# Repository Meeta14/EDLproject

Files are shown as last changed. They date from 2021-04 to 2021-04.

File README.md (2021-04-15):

# EDLproject

Contains the code for measuring the State-of-Charge (SoC) of Lead-acid battery and also the PCB design of an analog circuit designed for LED intensity control of Solar-powered street lights.

Below are the schematic and board diagrams of the above-mentioned PCB.

sche
brd

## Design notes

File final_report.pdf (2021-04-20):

## Electronic Design Lab - EE 344

### Group - 33

## Solar-powered Street Light: LED intensity control

### Team Details

Group- 33

1. Avyakta Wrat - 180070010
2. Hitesh Kandala - 180070023
3. Meeta Malviya - 180070034

### Faculty Mentor

Prof Joseph John

### Problem Statement

At times due to cloudy sky or rain the solar panel present in the street light cannot produce the required amount of energy required to charge the battery. Full load is applied to this uncharged battery and hence the working time of the street light is low. Using battery at full load when it is low on charge, can damage it.
To address the above mentioned problem, we were expected to design a LED intensity control based on the state-of-charge (SoC) of the battery.

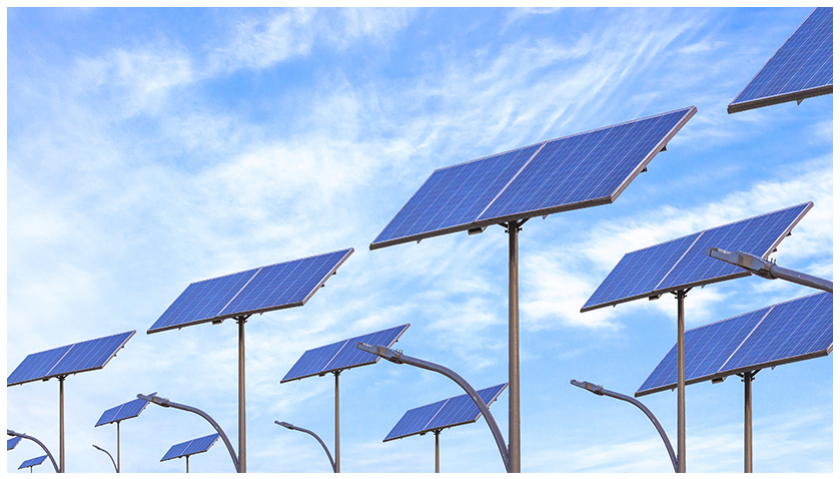
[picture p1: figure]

Figure 1

1

## 1 Design Approach

One of the possible solutions to vary the intensity of the LED lights is by varying the PWM’s duty cycle of the input voltage to the load LED’s. The proposed solution uses 555 Timer to vary the pulse width from 100% to 50% depending upon the battery voltage, hence increasing the discharge time of the battery and reducing the LED intensity by half. Using this, the street lights can be used for prolonged duration.

### 1.1 Proposed circuit

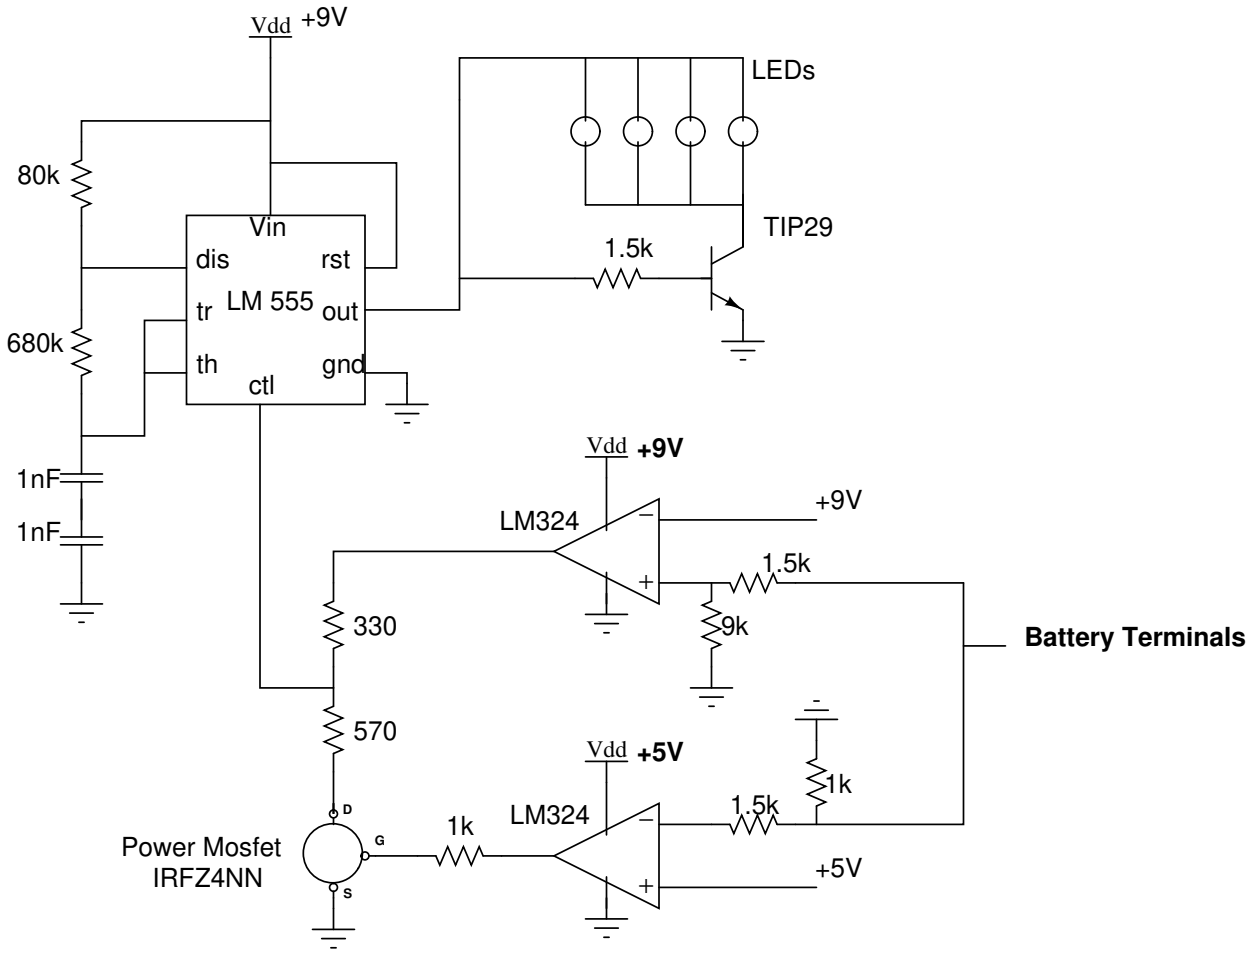
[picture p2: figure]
Vin; dis; rst; out; ctl; gnd; Vdd; Vdd +9V; LEDs; Power Mosfet; Battery Terminals 330; IRFZ4NN; TIP29

9V and 5V are supplied from respective voltage regulators

Figure 2

2

### Battery

1. The battery used is Panasonic UP-PW1245P1.
2. The Voltage when full charged is 12.7V
3. The battery has 50% charge at 11.6V.
4. The battery charge is below 10% or dead when no load voltage is 10.5V
5. Internal resistance of the battery is 20mΩ.

### Voltage regulators

In the design we have used 9V and 5V which are to be produced using voltage regulators.

To produce 9V | To produce 5V
The IC used to generate 9V output is LM7809. It gives 9V for Vin upto 24V The peak current can go upto 2.2A | The IC used to generate 5V output is LM7805. It gives 5V for Vin upto 20V The peak current can go upto 2.2A

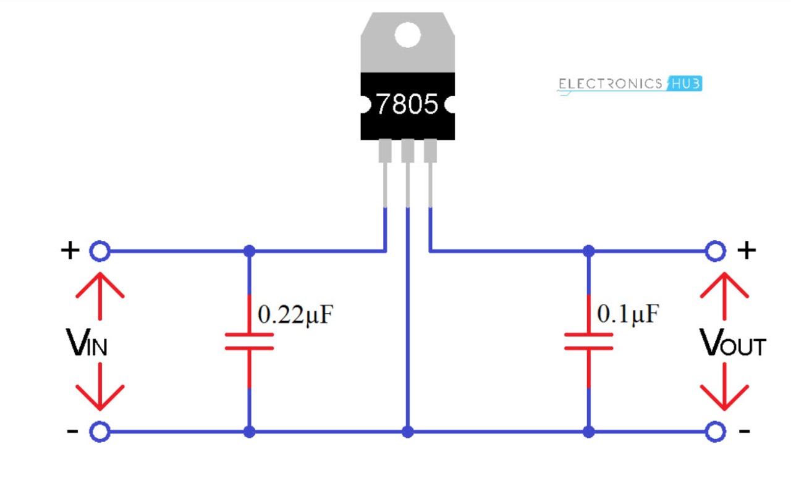
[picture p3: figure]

Figure 3: How to connect Voltage regulators

The above figure shows how voltage regulators must be connected in the circuit.
NOTE: This circuit is not shown in the above circuit, Voltages of 9V and 5V are shown independently to avoid unnecessary confusion.

3

### Timers

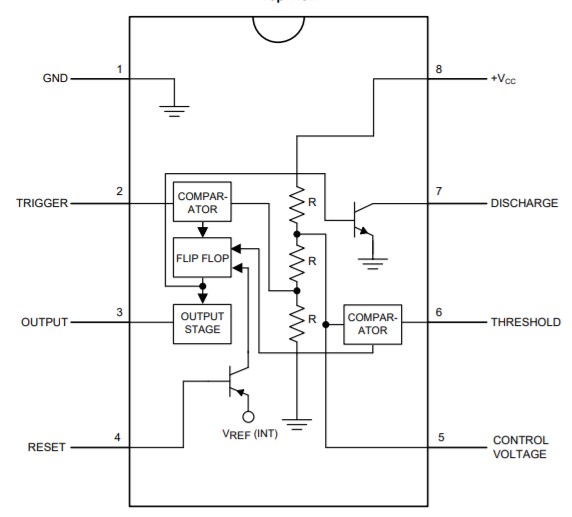
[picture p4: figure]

Figure 4

1. The 555-Timer used in the circuit is LM-555
2. Vcc can be from 5V-15V.
3. Vctl is used to vary the PWM cycle of the timer.

### 1.2 Calculations for Load and it’s specifications

The load that is being used is 5W LED strips.
The current required to be fed to the 5W load to operate it at full load is:

Pload = 5W
Vout (from 555 timer) = 9V

Iload =

Pload

Vout

= 555.56 mA

The resistor needed to maintain the current with the BJT used is derived as follows:

β = 100; | VB = 0.7 V
IC = Iload = 555.56 mA; | IB = 5.56 mA

RB =

9 − VB
IB
∴ RB = 1.49 kΩ ≈ 1.5 kΩ

The NPN transistor BJT used is TIP29-BP, which has max collector current (Ic) =1A specifications.

4

### 1.3 Calculations Duty cycle and frequency

With control voltage applied at pin 5, we can control duty cycle and freq as follows:

1. Let voltage applied at pin 5 be Vctl and Vctl <= 9 V.
2. Then the voltages map as follows:
2
3

Vcc −→ Vctl

1
3

Vcc −→

Vctl
2
3. Calculating “On” (charging) time:
Taking the moment that the capacitor starts charging to be t = 0 we can state the charging equation for the capacitor as:

V (t) = (Vcc − 0.5Vctl)(1 − e

−t
τc ) + 0.5Vctl

where, charging time constant τc = (RA + RB)C Now, V (ton) = Vctl gives:
ton = τc ln
Vcc − 0.5Vctl

Vcc − Vctl

4. Calculating “Off” (discharging) time:
Now we will show that the ”off” time is not dependent on Vctl. We know that a discharging capacitor can be modeled with the following relation:

V (t) = V0e

−t
τd

where, V0 = Vctl i.e initial voltage and discharging time constant τd = RBC Now, V (tof f ) = 0.5Vctl gives:

tof f = τd ln (2)

5. Duty cycle is given as follows:

D =

ton

ton + tof f

=

τc ln (Vcc−0.5Vctl
Vcc−Vctl

)

τc ln (Vcc−0.5Vctl
Vcc−Vctl

) + τd ln (2)

6. Frequency is given as:

f =

1

ton + tof f

=

1

τc ln (Vcc−0.5Vctl
Vcc−Vctl

) + τd ln (2)

To maintain the clock frequency around 1kHz, we choose RA = 80 kΩ, RB = 680 kΩ and C = 0.5 nF.
So, in our case when Vcc = 9V , for achieving 100% duty cycle, Vctl should be 9V and for achieving 50% duty cycle, Vctl should be 5.68V. As we can observe that the frequency varies as Vctl varies. Hence for 100% PWM the frequency is around 1kHz, for 50% it is 2kHz.

5

### 1.4 Switching Circuit

The OPAMP used for the circuit as a comparator is LM324.The supply voltage can be of 3V-32V. The maximum output current is of 20mA
The switching logic creates the output such that,
1. The OP-AMP-1 outputs 1 (high=9V) when the battery voltage is more than 10.5V.
2. The OP-AMP-2 outputs 1 (high=5V) when the battery voltage is less than 11.6V
3. Then the output of OP-AMP -2 decides whether the MOSFET is supposed to turn on or off.
4. The VDD is 0V (output low of OM-AMP1) when battery is dead.
OP AMP1/2 = ON/OF F | MOSF ET = OF F , Vout = Vctl = 9V
OP AMP1/2 = ON/ON | MOSF ET = ON, Vout = Vctl = 5.68V ≈ 5.7V
OP AMP1 = OF F | Vout = Vctl = 0V

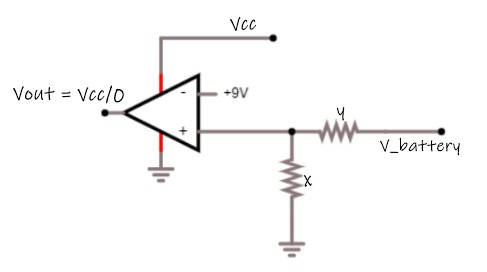
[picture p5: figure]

(a) Opamp 1

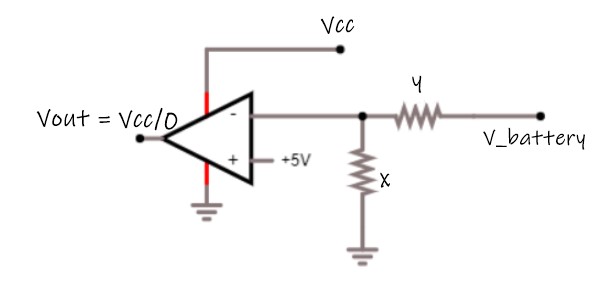
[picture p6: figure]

(b) Opamp 2

Figure 5

OP-AMP-1 Calculations
We want output high for VBattery > 10.5, I have put a V− = 9V , hence,

V− = 9V > V+; Vbattery ≤ 10.5

9 ≥ Vbattery ×

x
x + y
9x + 9y ≥ 10.5x
9y ≥ 1.5x
Chosen resistor values are x = 1.5kΩ; y = 9kΩ

6

OP-AMP-2 Calculations
We want output low for 12.7 > VBattery > 11.6, I have put a V+ = 5V , hence,

V+ = 5V > V−; 11.6 ≤ Vbattery ≤ 12.7

11.6 ×

x
x + y

≤ 5 ≤ 12.7 ×

x
x + y
11.8x ≤ 5x + 5y ≤ 12.7x
6.8x ≤5y ≤ 7.7x
1.36x ≤y ≤ 1.54x
Chosen resistor values are x = 1kΩ; y = 1.5kΩ

MOSFET Calculations
The MOSFET we decided to use is IRFZ44N. It has a max Gate threshold of 4V.The VGS can go upto 20V. It has a max current rating of 49A.
MOSF ET = ON | VGS = 5V | Vth = 4V | VDD = 9V
MOSF ET = OF F | VGS = 0V | Vth = 4V | VDD = 9V

As noted in the above section for 50% cycle we need to have Vout = 5.68 ≈ 5.7V

Functioning of the MOSFET as a switch can be denoted by the following figure.

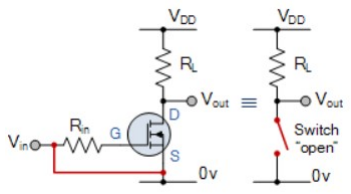
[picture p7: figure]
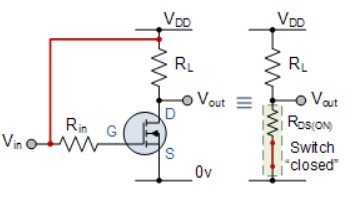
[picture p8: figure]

(a) switch on | (b) switch off

Figure 6

1. The internal resistance of the MOSFET RDS is of 19mΩ and hence is neglected.
2. We need to drop the potential of 9V to 5.7 volts and give it as input to 555 timer.
3. This is achieved by using 570Ω (470 + 100) and 330Ω resistors.
4. The max current through OMAMP and MOSFET is of 10mA which is well below the max rated current.

7

### 1.5 Proposed method for SOC calulations

To calculate the SOC,

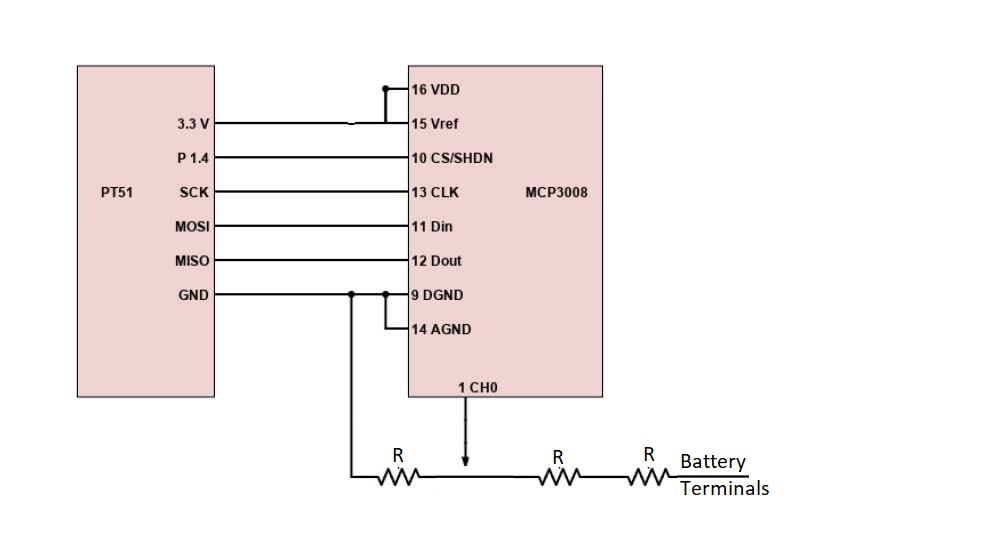
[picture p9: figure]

Figure 7: connections for pt-51

1. We are using IC MCP3008 (10-bit Analog-to-Digital converters (ADC) with SPI) to calcuate the voltage across the battery.
2. The circuit is connected as shown above.
3. The output of the IC is in the format: XXXXX mV, hence even after using the voltage divider we have not compromised much on the precision.
4. The range of output will be

10.5V ≤ 3Vmeasured ≤ 12.7V 3.5V ≤ Vmeasured ≤ 4.23V

5. We measure the 10 instances of the battery voltage and take the minimum voltage. This voltage will correspond to when LEDs are on (given the measured voltage is more than 10.5V).

8

6. Because we want open circuit voltage we make the following calculations (done by micro controller)

Vbattery − ItotalRinternal = Vmeasured
V measured = (measurement made by ADC) × 3 Itotal ≈ 560mA (when LED’s are on)

Rinternal = 20mΩ

Vbattery = ItotalRinternal + Vmeasured = 0.0112V + Vmeasured

The link to the codes for the above method is, https://github.com/Meeta14/EDLproject

### 1.6 Cost of Billing

The total cost is shown below,
NOTE: Panasonic UP-PW1245P1 of worth Rs. 2252 and LED load is taken as given.
Item | Quantity | Single Unit Price (Rs) | Total Price (Rs)
LM324 | 2 | 11 | 22
LM555 | 1 | 10 | 10
IC 7805 | 1 | 9 | 9
IC 7809 | 1 | 10 | 10
IRFZ44N | 1 | 20 | 20
TIP29 BJT | 1 | 32 | 32
100Ω Resistor | 1 | 0.5 | 0.5
330Ω Resistor | 1 | 2 | 2
470Ω Resistor | 1 | 1 | 1
1kΩ Resistor | 2 | 0.5 | 1
1.5kΩ Resistor | 3 | 1 | 3
9kΩ Resistor | 1 | 1 | 1
40kΩ Resistor | 3 | 1 | 3
80kΩ Resistor | 1 | 1 | 1
680kΩ Resistor | 1 | 2 | 2
1nF Capacitor | 2 | 0.5 | 1
0.1uF Capacitor | 2 | 0.5 | 1
0.22uF Capacitor | 2 | 0.5 | 1
| | Total Cost | 120.5

NOTE: The cost of PCB printing is not included in it.

9

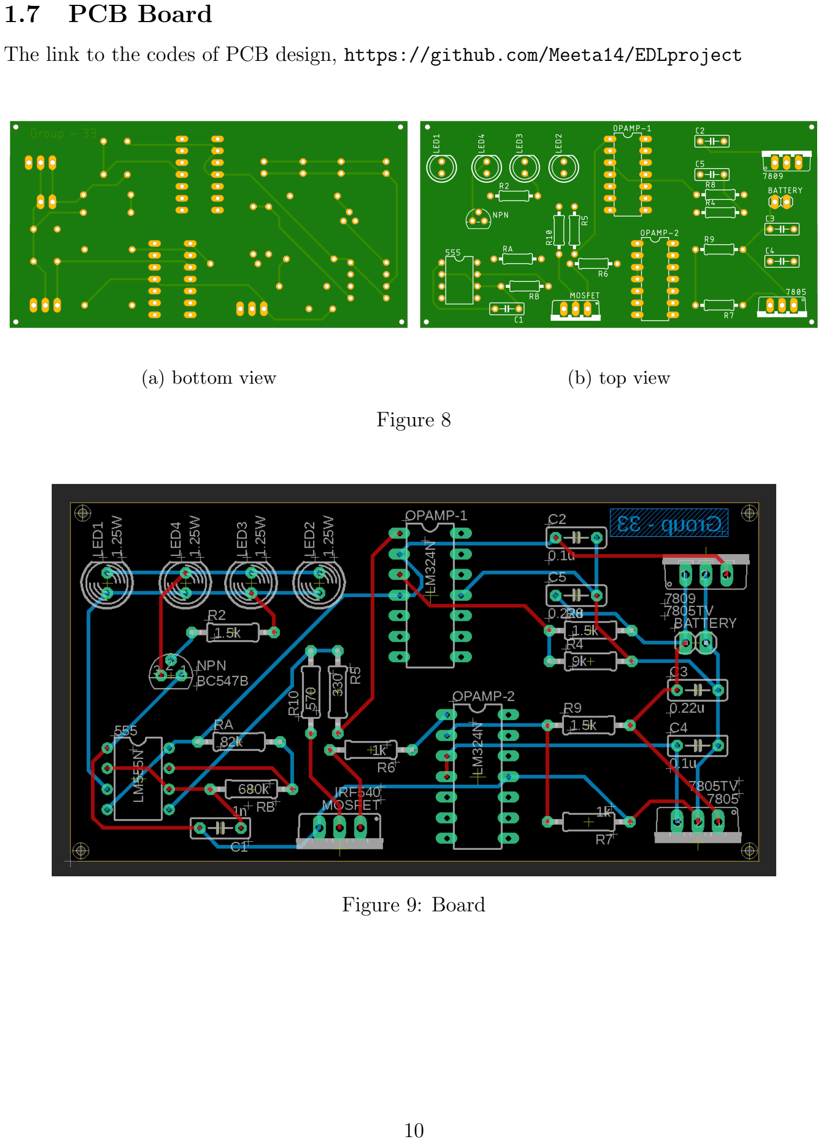
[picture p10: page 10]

### 1.7 PCB Board

The link to the codes of PCB design, https://github.com/Meeta14/EDLproject

(a) bottom view | (b) top view

Figure 8

Figure 9: Board

10

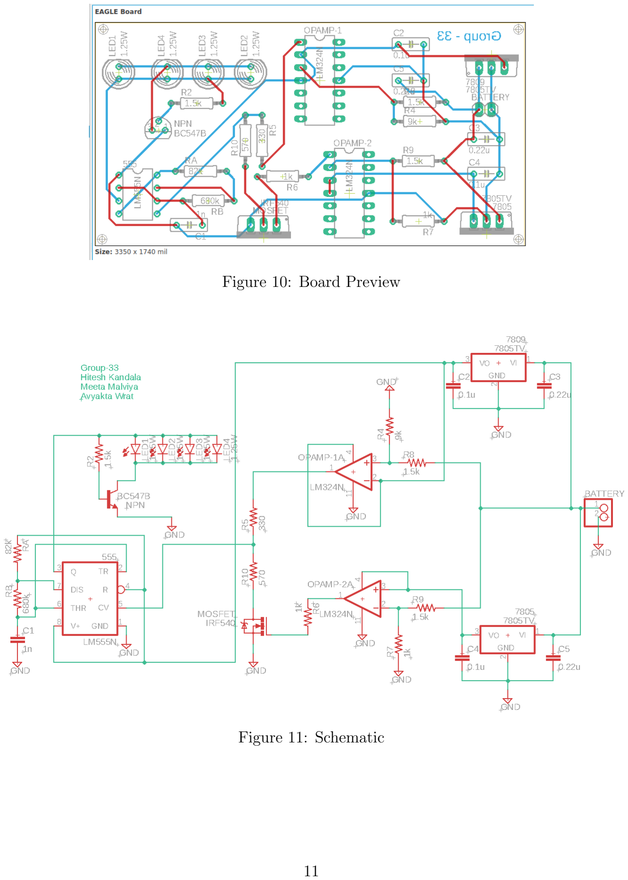
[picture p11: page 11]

Figure 10: Board Preview

Figure 11: Schematic

11

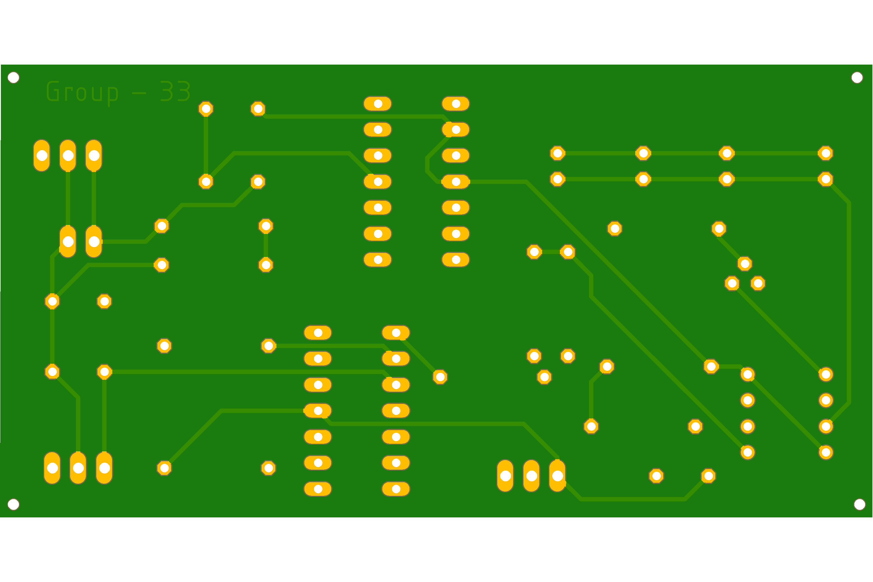
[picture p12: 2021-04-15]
pcb-design/pcb_bottom.png

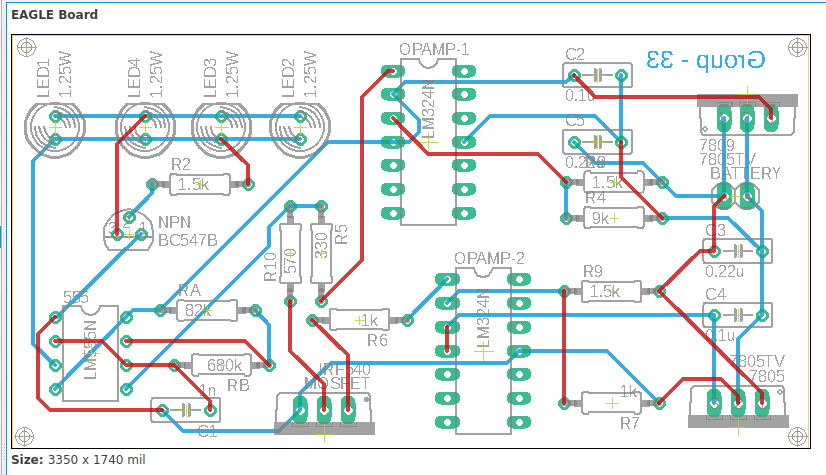
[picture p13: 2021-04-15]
pcb-design/preview.png

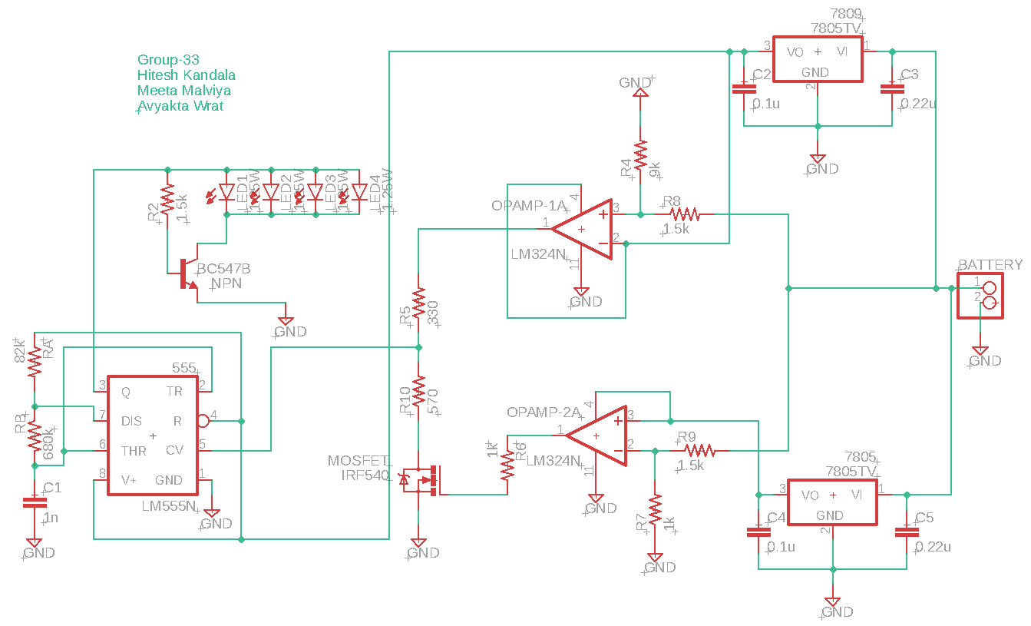
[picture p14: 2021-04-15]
pcb-design/sche.png

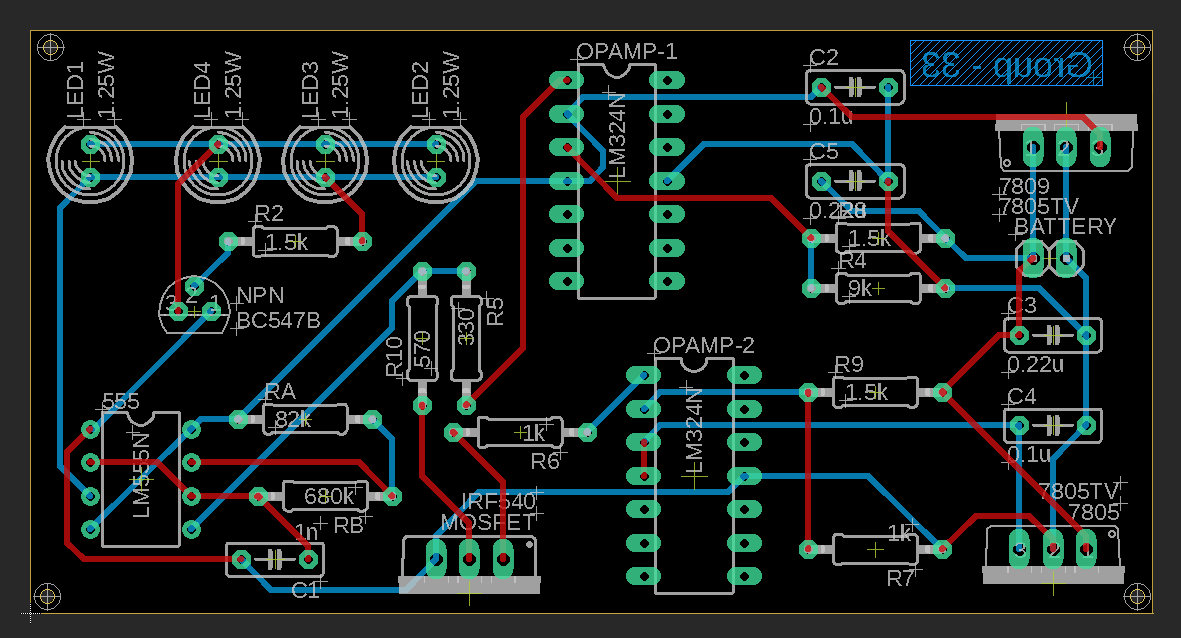
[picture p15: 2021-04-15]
pcb-design/brd.png

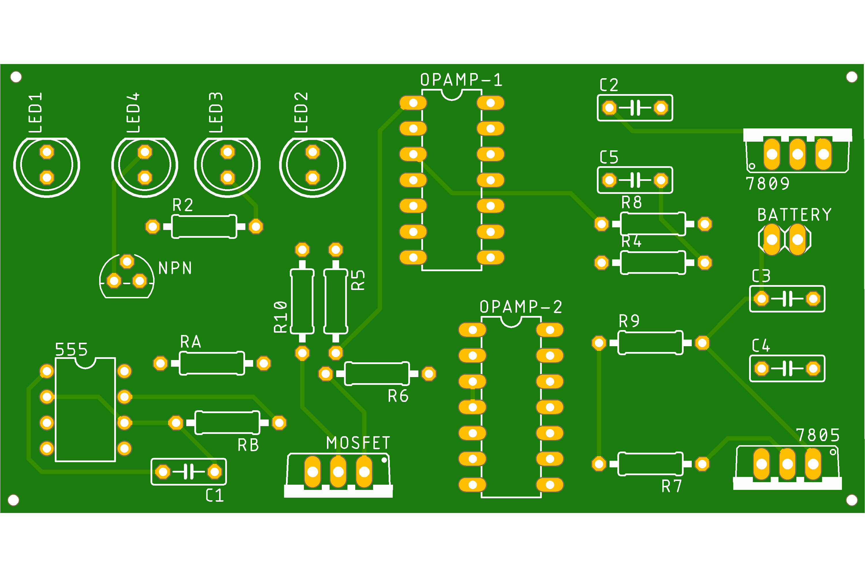
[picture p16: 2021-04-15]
pcb-design/pcb_top.png

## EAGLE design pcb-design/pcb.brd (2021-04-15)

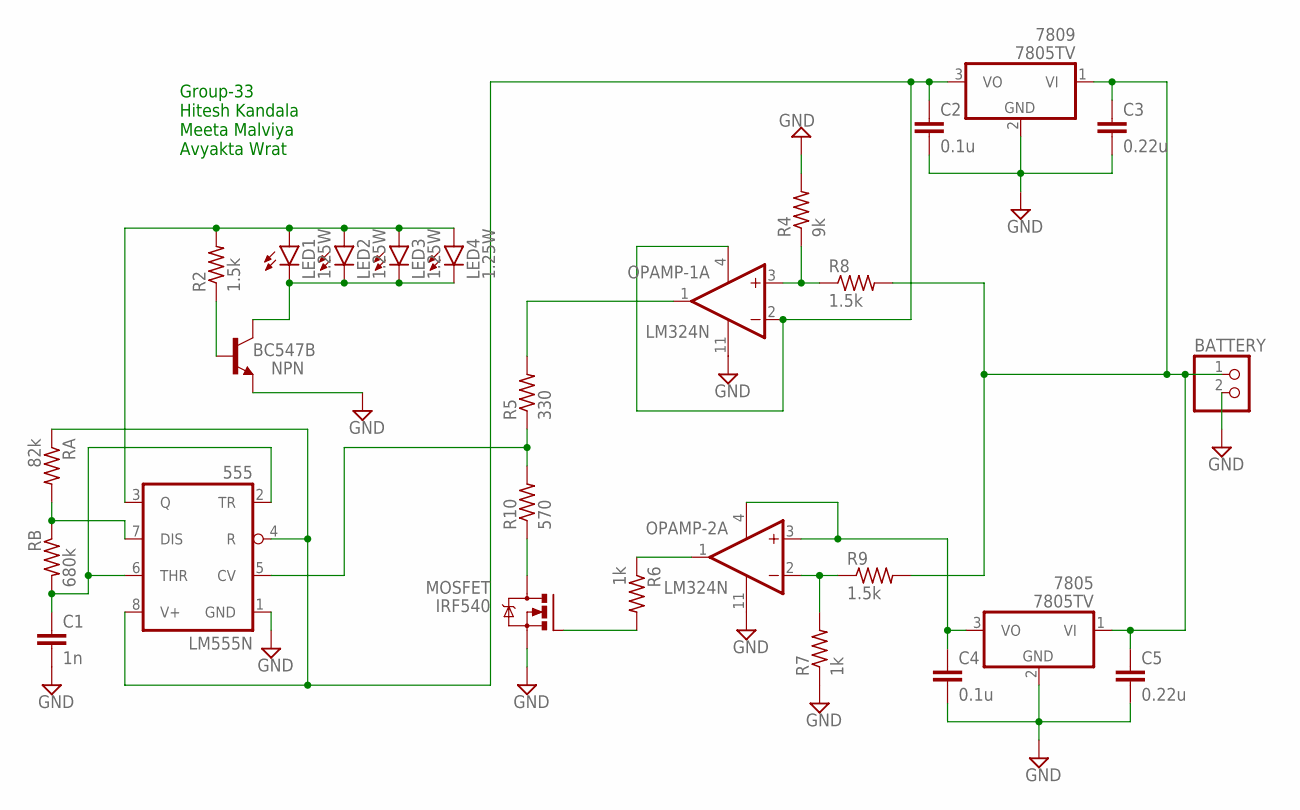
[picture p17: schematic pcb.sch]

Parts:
555: LM555N; DIL08
7805, 7809: 7805TV; TO220V
BATTERY: PINHD-1X2; 1X02
C1: 1n; C050-025X075
C2, C4: 0.1u; C050-025X075
C3, C5: 0.22u; C050-025X075
LED1, LED2, LED3, LED4: 1.25W; LED5MM
MOSFET: IRF540; TO220BV
NPN: BC547B; TO92
OPAMP-1, OPAMP-2: LM324N; DIL14
R2, R8, R9: 1.5k; 0207/10
R4: 9k; 0207/10
R5: 330; 0207/10
R6, R7: 1k; 0207/10
R10: 570; 0207/10
RA: 82k; 0207/10
RB: 680k; 0207/10

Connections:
GND: 555.1 (GND), 7805.2 (GND), 7809.2 (GND), BATTERY.2, C1.2, C2.2, C3.2, C4.2, C5.2, MOSFET.S, NPN.1 (E), OPAMP-1.11 (V-), OPAMP-2.11 (V-), R4.2, R7.1
unnamed: 555.4 (R), 555.8 (V+), 7809.3 (VO), C2.1, OPAMP-1.2 (-IN), OPAMP-1.4 (V+), RA.1
unnamed: 555.2 (TR), 555.6 (THR), C1.1, RB.2
unnamed: 555.3 (Q), LED1.A, LED2.A, LED3.A, LED4.A, R2.2
unnamed: 555.7 (DIS), RA.2, RB.1
unnamed: 7805.1 (VI), 7809.1 (VI), BATTERY.1, C3.1, C5.1, R8.2, R9.2
unnamed: NPN.2 (B), R2.1
unnamed: OPAMP-1.3 (+IN), R4.1, R8.1
unnamed: OPAMP-2.2 (-IN), R7.2, R9.1
unnamed: 7805.3 (VO), C4.1, OPAMP-2.3 (+IN), OPAMP-2.4 (V+)
unnamed: OPAMP-2.1 (OUT), R6.1
unnamed: 555.5 (CV), R5.1, R10.2
unnamed: OPAMP-1.1 (OUT), R5.2
unnamed: MOSFET.D, R10.1
unnamed: MOSFET.G, R6.2
unnamed: LED1.K (C), LED2.K (C), LED3.K (C), LED4.K (C), NPN.3 (C)

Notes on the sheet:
Group-33 Hitesh Kandala Meeta Malviya Avyakta Wrat

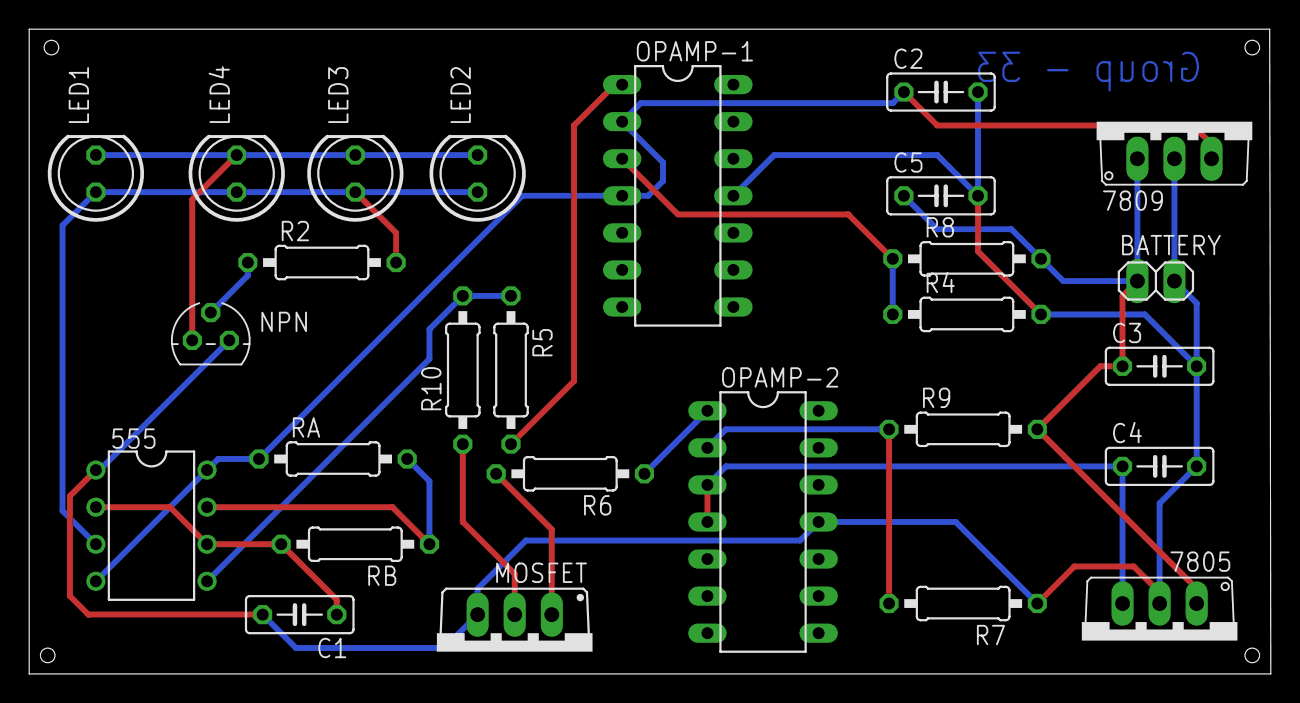
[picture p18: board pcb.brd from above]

Board: 2 copper layers, 85.1 x 44.2 mm, 27 parts (0 on the bottom side), 16 nets.

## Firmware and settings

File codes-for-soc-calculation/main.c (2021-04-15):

/********************
EE337: ADC IC MCP3008 interfacing with pt-51
(1) Complete spi_init() function from spi.h 
(2) Uncomment LM35 interfacing code from main function
		Choose appropriate scaling factor for converting temperature 
		sensor reading sampled using ADC such that it will be in 
		degree Celsius and display it on the LCD)
*********************/

#include <at89c5131.h>
#include "lcd.h"																				//Driver for interfacing lcd 
#include "mcp3008.h"																		//Driver for interfacing ADC ic MCP3008


char adc_ip_data_ascii[6]={0,0,0,0,0,'\0'};							//string array for saving ascii of input sample
code unsigned char display_msg1[]="Volt.: ";						//Display msg on 1st line of lcd
code unsigned char display_msg2[]=" mV";								//Display msg on 2nd line of lcd
unsigned char display_msg3[]={0,0,0,'.',0,' ',223,'C','\0'};//"xxx °C", Display msg on 2nd line of lcd
code unsigned char display_msg4[]="Temp.: ";						//Display msg on 2nd line of lcd
unsigned int array_adc[10];
unsigned int idx=0;
unsigned int x;	
unsigned int min_value=0;
unsigned int i=0;

void msdelay2(unsigned int time)
{
	int i,j;
	for(i=0;i<time;i=i+2)
	{
		for(j=0;j<382;j=j+2);
	}
}

void main(void)
{
	int j=0;
	unsigned int adc_data=0;
	//float temperature;
	
	spi_init();																					
	adc_init();
  lcd_init();	
	
	while(1)
	{
		if(idx==9){	                            // when we have completed 10 instances of measurement
			i=0;
			min_value=array_adc[0];
			for(i=1;i<10;i++){                     // find the minimum voltage
					if(min_value>array_adc[i]){
						min_value=array_adc[i];
					}
			}
			adc_data = (unsigned int) (min_value*3.2258); 							//Converting received 10 bits value to milli volt (3.3*1000*i/p /1023)	
			lcd_cmd(0x80);																			//Move cursor to first line
			lcd_write_string(display_msg1);											//Display "Volt: " on first line of lcd
			
			if(adc_data>10500){                                // if the voltage is more than 10% V ratings we add the  IR component
					adc_data=adc_data+0.0112;
			}
			int_to_string(adc_data,adc_ip_data_ascii);					//Converting integer to string of ascii
			
			lcd_write_string(adc_ip_data_ascii);								//Print analog sampled input on lcd
			lcd_write_string(display_msg2);											//Display "XXXXX mV"
					
			idx=0;
		}
	 	 
		x = adc(0);																					//Read analog value from 0th channel of ADC Ic MCP3008
    array_adc[idx] = x;                                // keep the array updated
		msdelay2(2);
	}
}

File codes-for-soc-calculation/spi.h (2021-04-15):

/**********************************************************
This header file contains function related uC 8051 SPI module. 
It has functions to initialize spi module and to communicate with SPI slave 
***********************************************************/

//preprocessor directives for guarding against multiple inclusion of header files, read compiler user guide for more information

#ifndef spi_h																						//if identifier spi_h is not defined then goto next line
	#define spi_h 1																				//Define spi_h identifier and assign constant 1 to it 
#endif																									//end if directive

//Declaration of functions which are contained in this header file

void spi_init(void);																		//Initialize SPI module 
unsigned long int spi_trx(unsigned long int spi_data_tx);				//Takes 3 bytes as an input and send it to SPI slave IC and returns 3 bytes which are received from slave
void spi_interrupt(void);																//SPI ISR 																												


//Variable declaration

bit transmit_completed= 0;															//To check if SPI data transmit is complete
unsigned char temp_spi_data;														//Temporary variable

//Function definition


/**********************************************************
  spi_init(): 
	
	Initialization function to be completed
	Initializes SPI peripheral for interfacing with MCP3008, 
	Choose appropriate SPCON value by referring to 
	MCP3008 and AT89C5131 datasheets  	
***********************************************************/
void spi_init(void)
{
	/*
			Configure SPCON=0x__ is not a bit addressable sfr
																												
			(1) Configure MSTR to set uC in Master mode
			(2) Configure SSDIS to disable SSBAR thus 
					P1.1(SSBAR) will be available as standard I/O pin 	             	 	 
			(3) Configure clock polarity s.t. sck from uC set to 0 in idle state
					Refer to SPCON register table no 19-3 from AT89C5131 datasheet
			(4) Configure clock phase i.e. CPHA: Refer SPI timing 
					diagram of ADC IC (figure no. 6-1 in MCP3008 datasheet)
					first and then table no 19-3, figure no. 19-4 to 19-6 in AT89C5131 datasheet
					to choose appropriate CPHA value
			(5) Fclk/16 & Fclk Periph=12MHz ,thus BAUD RATE=750KHz
	
			(6) Enable SPI interrupt (i.e. configure IEN1 and EA)
			(7) Enable SPI module (i.e. configure SPCON )
*/	
	SPCON =0x33;			//0011 0011																																																					
	IEN1|= 0x04;																						//enable spi interrupt IEN1 |= 0x__
	EA= 1;																									//enable interrupts EA=_; 
	SPCON|= 0x40;		//0100 0000
	//Enable spi module
/*	
	SPR2 SPEN SSDIS MSTR CPOL CPHA SPR1 SPR0
	MSTR 0->SPI as a Slave. 1-> SPI as a Master.
*/
}

/**********************************************************
  spi_trx(): 
	
	Transmits 3 bytes to SPI slave and receive 3 bytes. 
	These 3 bytes are packed into 4 bytes as long datatype.
***********************************************************/
unsigned long int spi_trx(unsigned long int spi_data_tx)
{
	//declaration of local variables 
	unsigned long int spi_data_rx;
	unsigned char spi_data_3,spi_data_2,spi_data_1;
	
	//Send 3rd byte
		transmit_completed = 0;
		
		SPDAT = (spi_data_tx>>16)%256;											//Sending most significant byte of data to SPI slave 
	
		while(!transmit_completed);													//Wait till transmission is complete. 	
			spi_data_3	=	temp_spi_data ;											//Most significant byte will be received  
	
	//Send 2nd byte
		transmit_completed=0;
		SPDAT = (spi_data_tx>>8)%256;												//Extracting and sending byte between MS and LS byte to SPI slave	
		
		while(!transmit_completed);													//Wait till transmission is complete.
			spi_data_2	=	temp_spi_data ;											//Save byte received from SPI slave
	
	//Send 1st byte
		transmit_completed=0;
		SPDAT = (spi_data_tx%256);													//Extracting least significant byte and sending it to spi slave	
		
		while(!transmit_completed);													//Wait till transmission is complete.
			spi_data_1	=	temp_spi_data ;											//Save byte received from SPI slave
			
		spi_data_rx= (spi_data_3<<16) + (spi_data_2<<8) + spi_data_1;			//Concatenate all received byte to form a 32 bit word
	
		return spi_data_rx;																	//return it	
}

/**********************************************************
  spi_interrupt() 
	
	Interrupt service routine for SPI interrupt.
	Generates interrupt if transmission and reception are complete.
	Transmit and receive function (defined above) monitor
	for these flags to check if data transfer is done.
***********************************************************/
void spi_interrupt(void) interrupt 9 										// interrupt address is 0x004B, (Address -3)/8 = interrupt no.
{
	
	switch	( SPSTA & 0xf0)         											//read and clear SPI status register, for more info: table no 76 from datasheet 
	{
		case 0x80:																					//SPIF is set i.e. SP data transfer is complete 
			temp_spi_data=SPDAT;  														//Read received data 
			transmit_completed=1;															//Set transmission complete flag 
 		break;

		case 0x10:
			
		break;
	
		case 0x40:
		break;
	}
}
